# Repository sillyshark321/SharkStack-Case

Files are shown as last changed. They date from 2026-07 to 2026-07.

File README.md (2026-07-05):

# Corne v3 Stacked Acrylic Case
The whole project fits on a 3mm or 1/8" thick, 24" x 12" sheet of acrylic.
<div align="center">
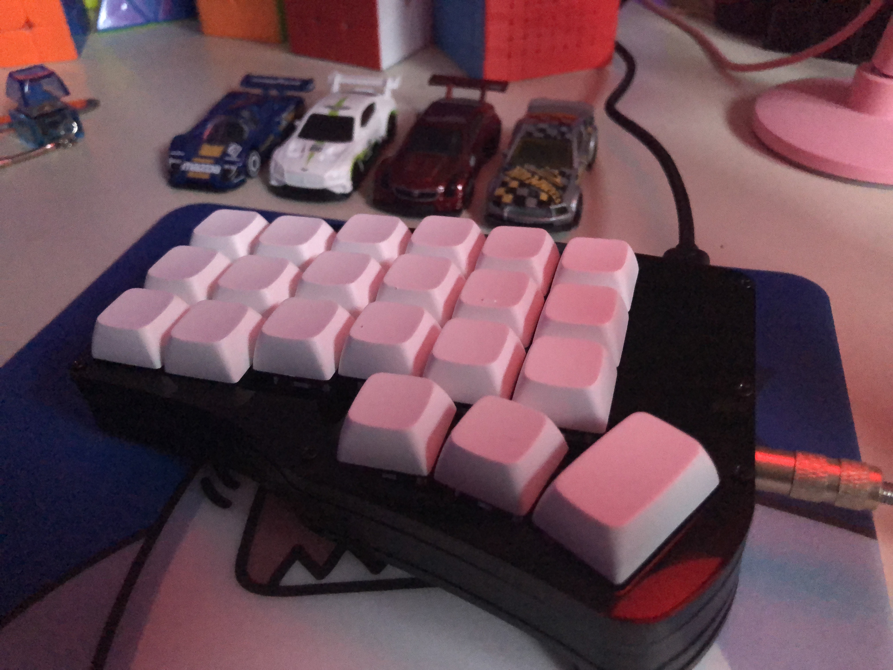
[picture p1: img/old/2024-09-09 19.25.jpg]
  
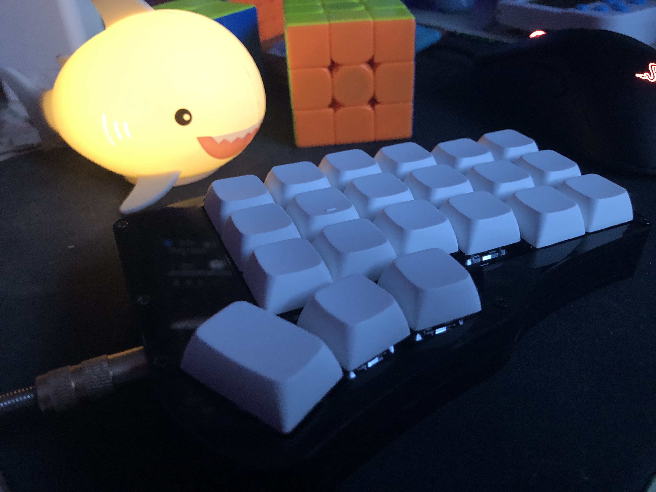
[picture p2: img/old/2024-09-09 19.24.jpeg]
  
</div>

<div align="center">
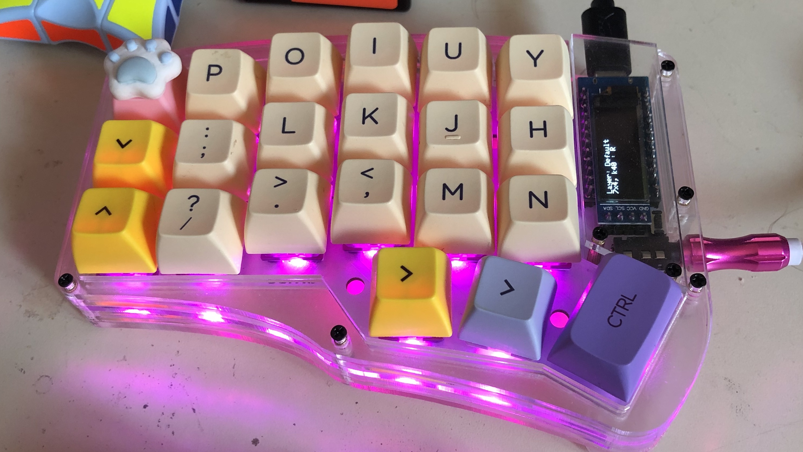
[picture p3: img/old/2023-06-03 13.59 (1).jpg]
  
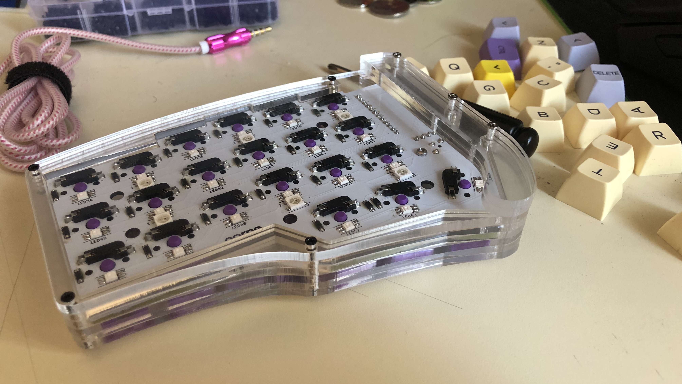
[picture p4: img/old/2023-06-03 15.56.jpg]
  
</div>

## Layers on cut file coloured
<div align="center">
  
</div>

## Materials List
| Material | Count | Notes |
| --- | --- | --- |
| **3 mm or 1/8" thick, 24" x 12" sheet of acrylic** | 1 | |
| **M2 x 12 mm standoffs** | 14 | You need 4 extra for the OLED cover (mounted to PCB)<br>I used 11 mm tall standoffs, works just fine |
| **M2 x 8 mm screws** | 22 | You need 28 without tenting |
| **M2 x 18 mm screws** | 6 | Only for tenting, adjust screw lengths if you wish to add more tenting layers |
| **Adhesive rubber feet** | 8 | Optional but highly recommended |

## Assembly
Finish your Corne v3 PCB first - I used [this guide](https://github.com/keyhive/build_guides/blob/master/docs/keyboards/crkbd-v3.md) from KeyHive

Download a .dxf file ([no OLED version](https://github.com/sillyshark321/SharkStack-Case/blob/main/dxf/sharkstack_noOLED.dxf) | [with OLED version](https://github.com/sillyshark321/SharkStack-Case/blob/main/dxf/sharkstack_withOLED.dxf)) and cut the patterns on your acrylic sheet. Make sure it is 3 mm thick.

Attach 4 standoffs to the outer sides of the base pieces, and screw them in with your short M2 screws.

<div align="center">
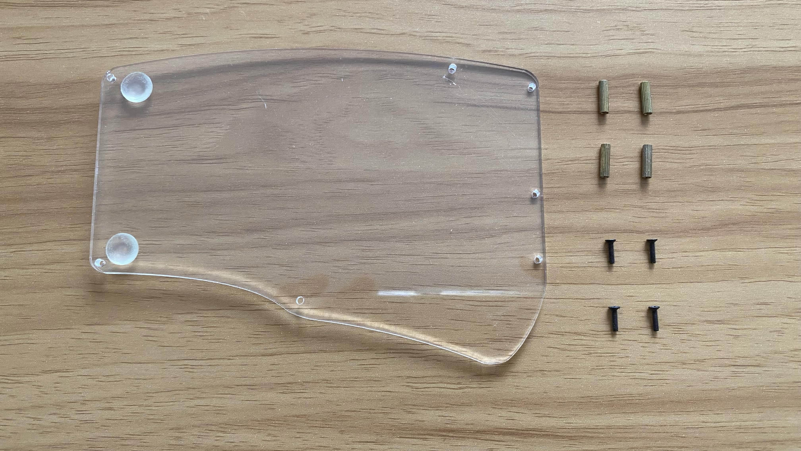
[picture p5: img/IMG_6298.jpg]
  
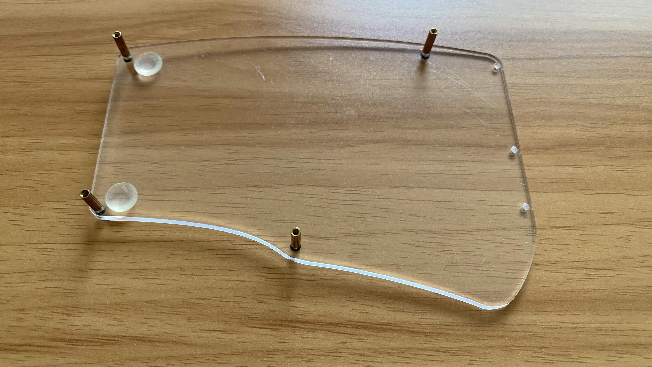
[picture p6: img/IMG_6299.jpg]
  
</div>

\
Stack your tenting layers (3 on each side in the cut file), and secure them to the base with the rest of your standoffs and your longer M2 screws.

<div align="center">
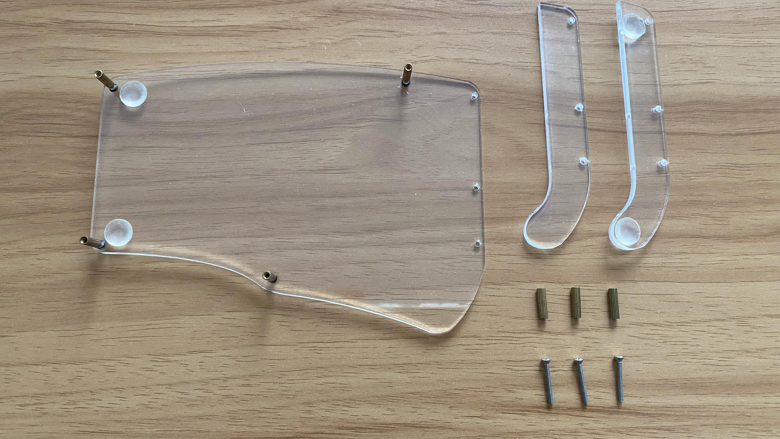
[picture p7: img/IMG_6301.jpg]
  
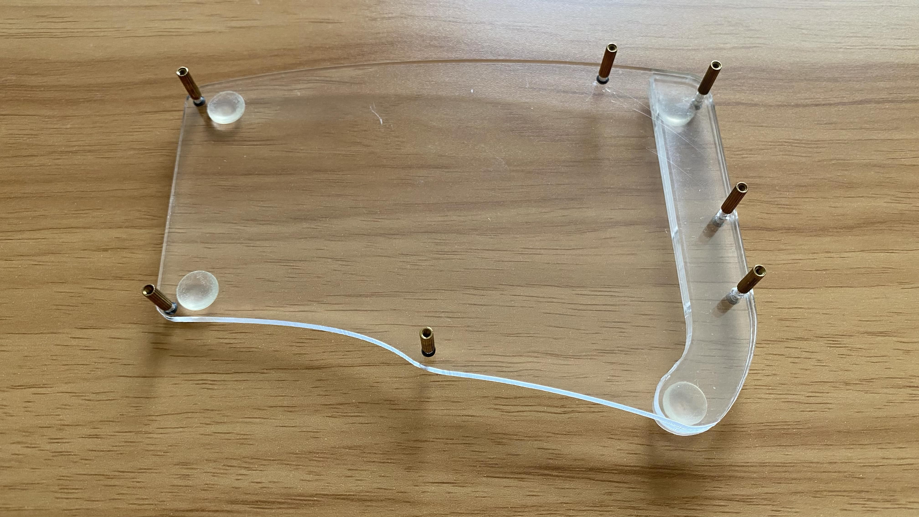
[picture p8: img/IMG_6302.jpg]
  
</div>

\
Add 2 big wall layers and 4 short wall layers through the standoffs, as shown here.

<div align="center">
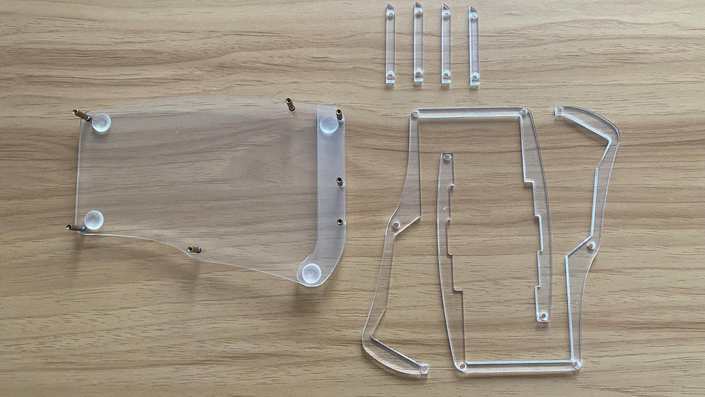
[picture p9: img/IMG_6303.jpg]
  
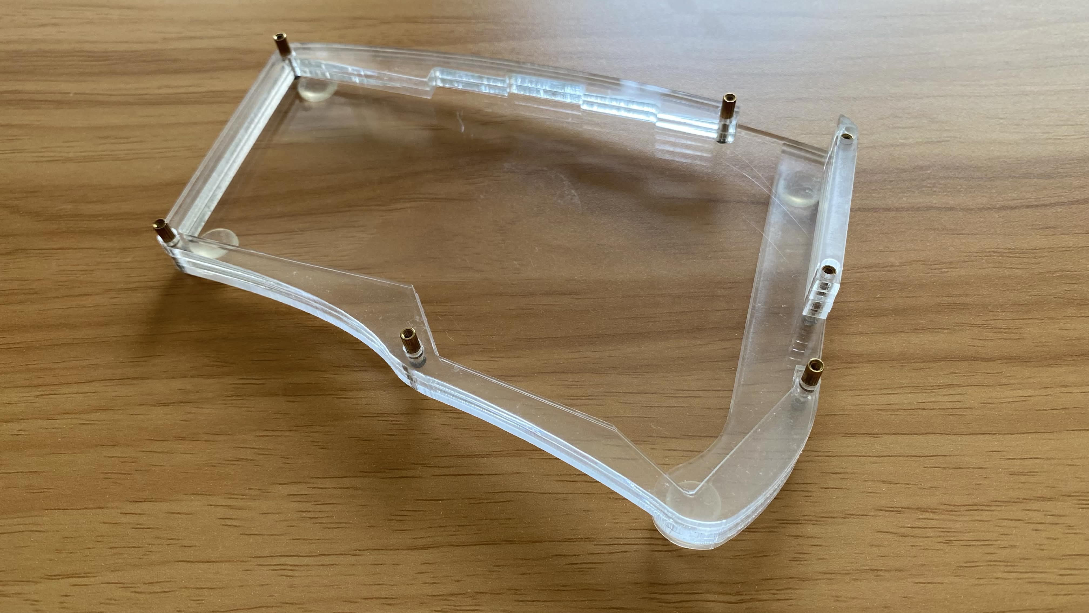
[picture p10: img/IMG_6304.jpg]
  
</div>

\
Add your desired switches onto your plate layers, and mount the Corne v3 PCBs to the switches. Put them in the case.\
Solder PCBs are recommended, but hotswap PCBs work fine too as long as you press firmly. Also attach your OLED covers with your extra standoffs if needed.

<div align="center">
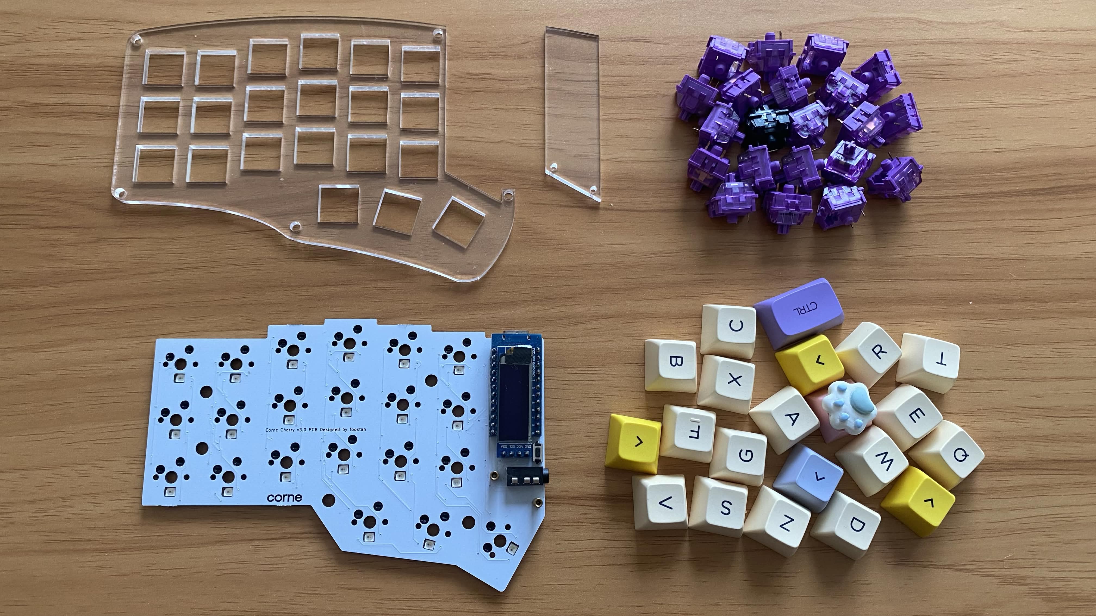
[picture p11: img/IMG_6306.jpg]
  
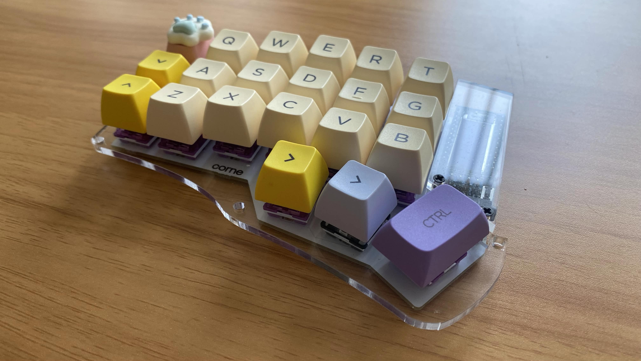
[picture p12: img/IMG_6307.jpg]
  
</div>

<div align="center">
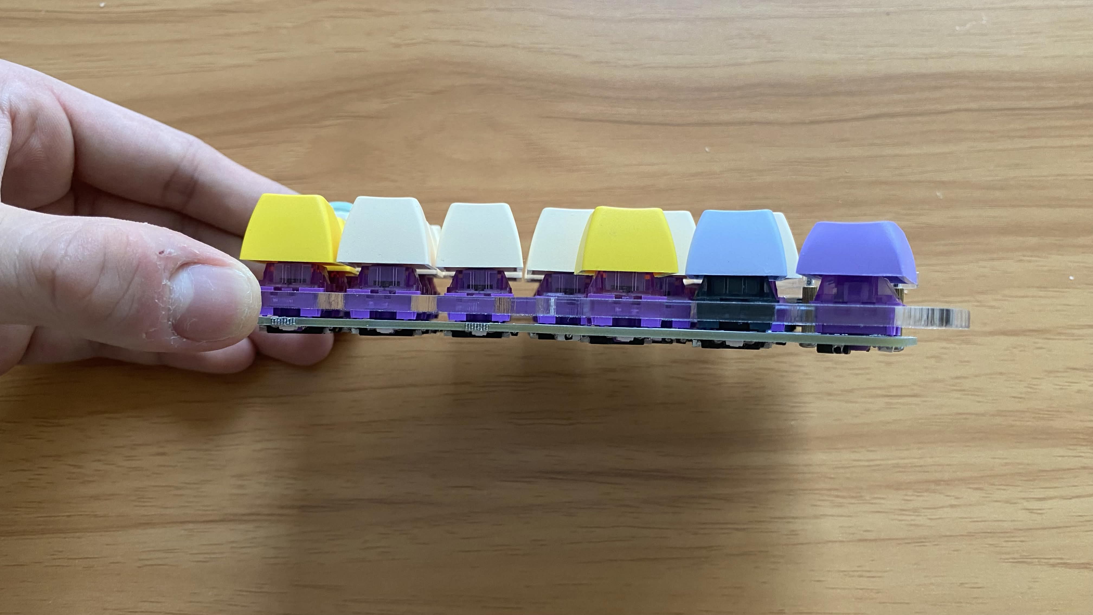
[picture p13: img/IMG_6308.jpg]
  
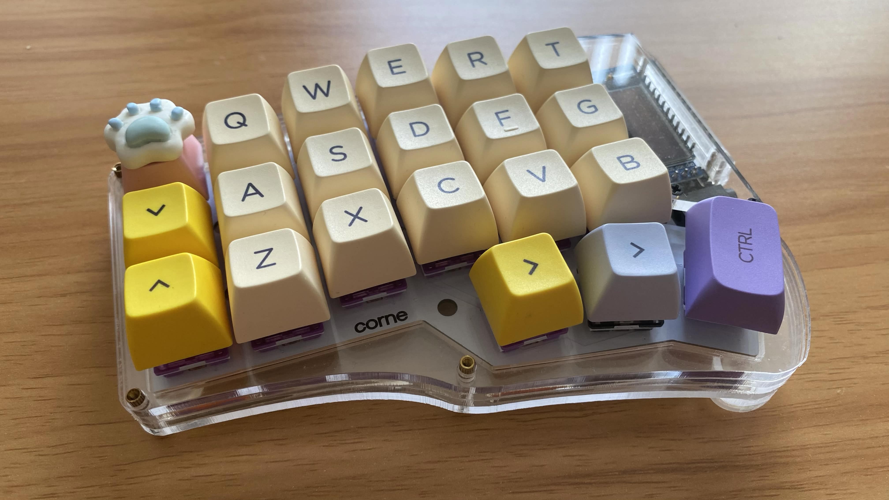
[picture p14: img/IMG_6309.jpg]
  
</div>

\
If you wish to use the version with no OLED cover, you may need to trim the pin headers, as this would happen otherwise.

<div align="center">
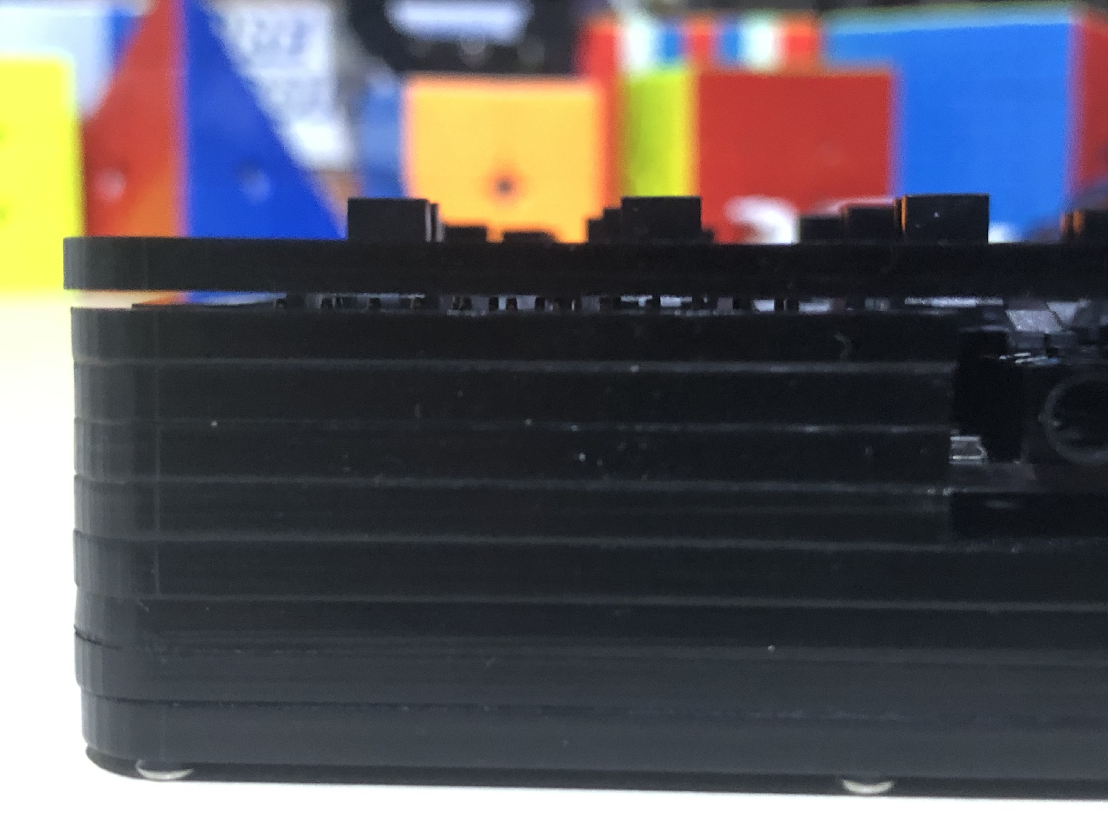
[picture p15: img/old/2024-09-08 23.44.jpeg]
  
</div>

\
Add the last wall layer, and add the top layer on top of the standoffs, and secure the case with the rest of your short M2 screws. Add adhesive rubber feet to finish it off.

<div align="center">
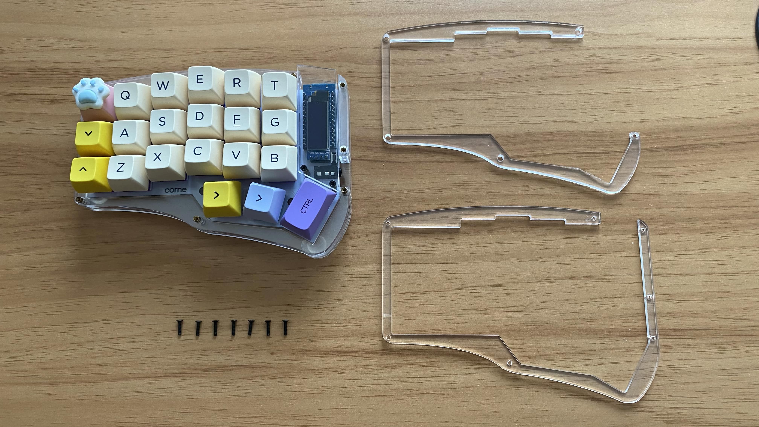
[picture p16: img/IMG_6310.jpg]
  
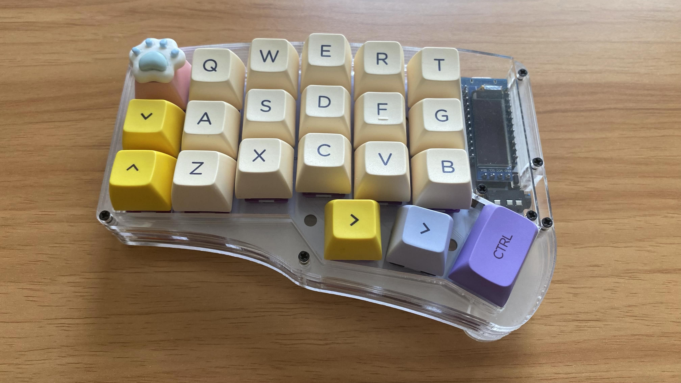
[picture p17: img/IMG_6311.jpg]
  
</div>

<div align="center">
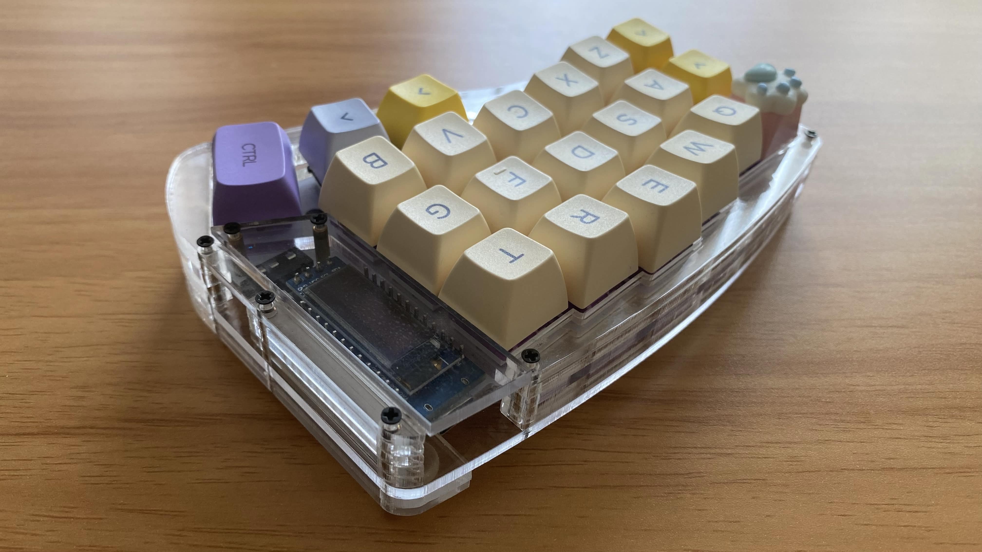
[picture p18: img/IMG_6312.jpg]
  
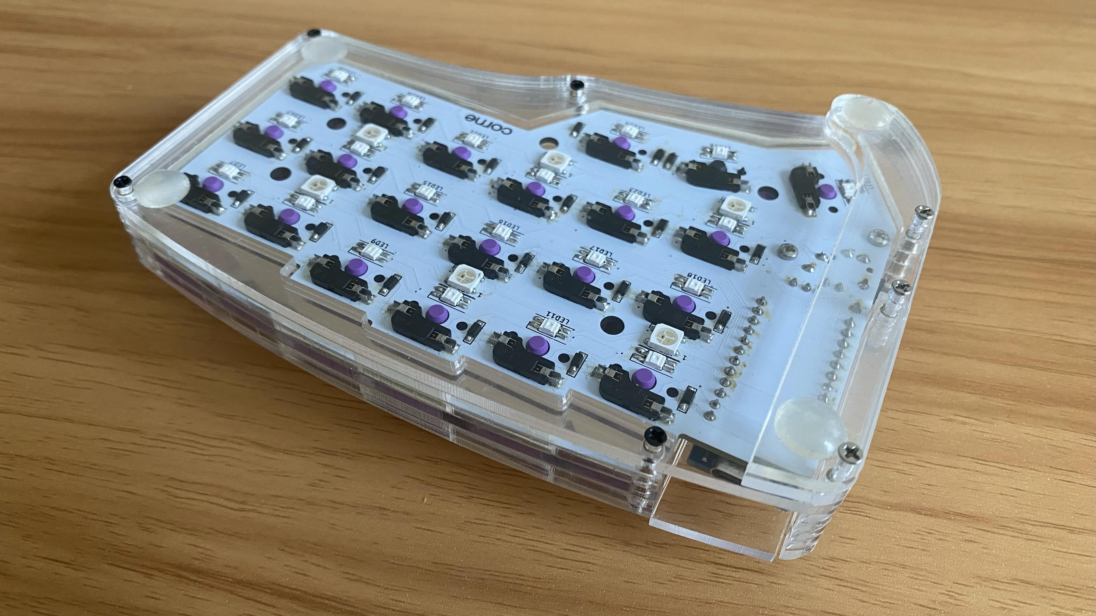
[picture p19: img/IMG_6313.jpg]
  
</div>

\
Repeat for the other half of your keyboard. Now you are done!
<div align="center">
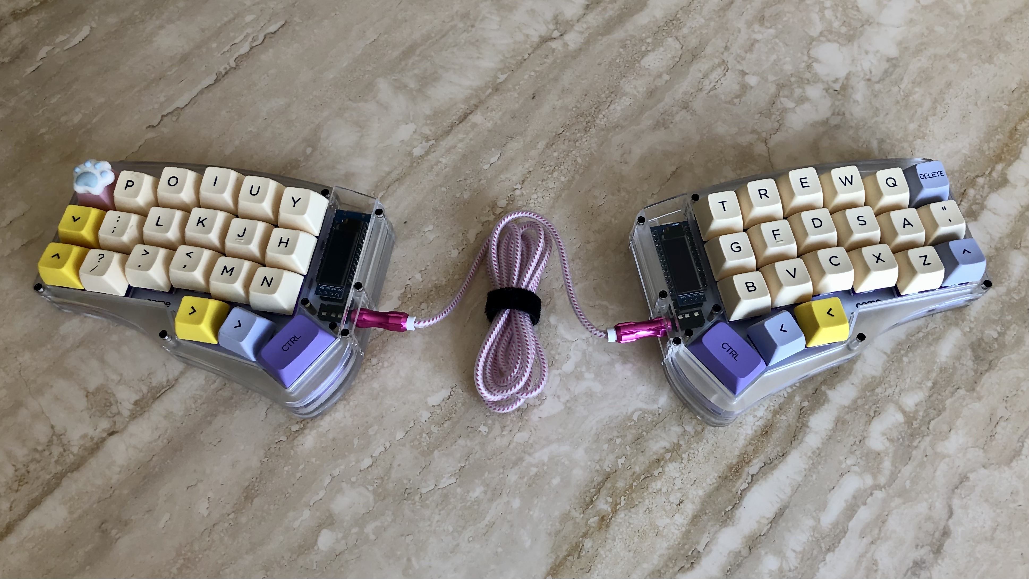
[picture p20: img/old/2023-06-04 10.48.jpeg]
  
</div>

## Watch me type because I'm pretty fast
<a href="https://www.youtube.com/watch?v=AXg2ITo80VI">
  <div align="center">
    
  </div>
</a>

## Other Links
This project was made possible (and heavily inspired) by Joe Scotto's keyboard case designing video:\
https://www.youtube.com/watch?v=7azQkSu0m_U

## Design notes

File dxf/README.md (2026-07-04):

# Cut Files
File names are self-explanatory. The only differences are the topmost layer, where a few extra cuts are included for the OLED covers.

All files have been tested with my two Corne builds. However, since they were backed up from another CAD software, the splines are slightly messed up and the cut lines aren't joined. I will take that into consideration when making future stacked acrylic keyboard cases.

## Author's Note
Turn up your cut strength settings slightly. I used the 60W Epilog Fusion Edge 24 and a few lines on the bottom half of my acrylic sheet didn't cut all the way through.

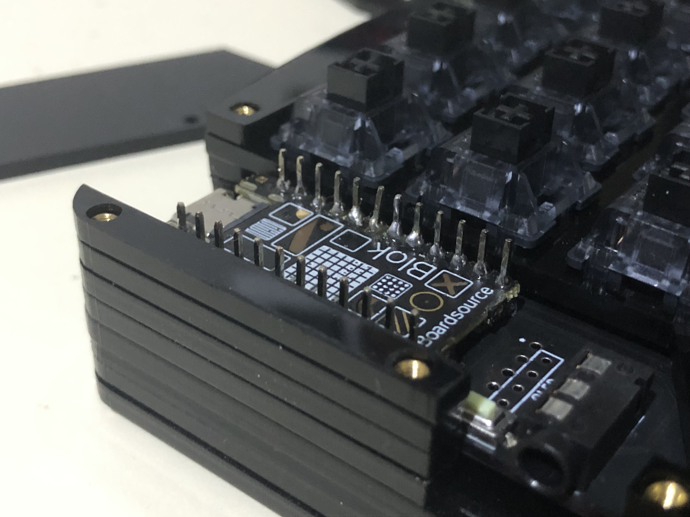
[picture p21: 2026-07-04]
img/2024-09-08 23.44 (1).jpeg

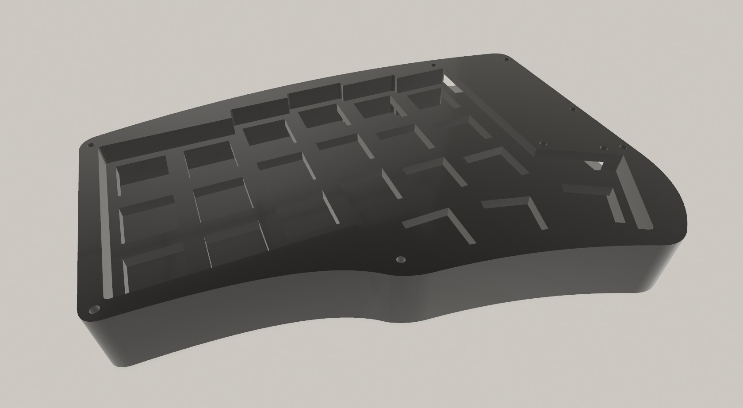
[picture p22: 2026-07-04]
img/2023-05-23 07.58.png

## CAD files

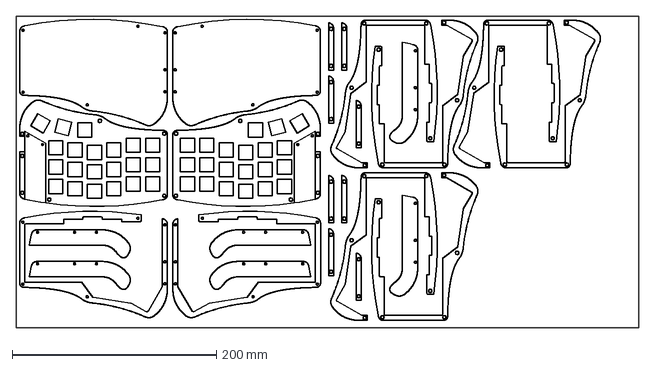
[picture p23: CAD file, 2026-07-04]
dxf/sharkstack_withOLED.dxf
609.6 x 304.8 mm

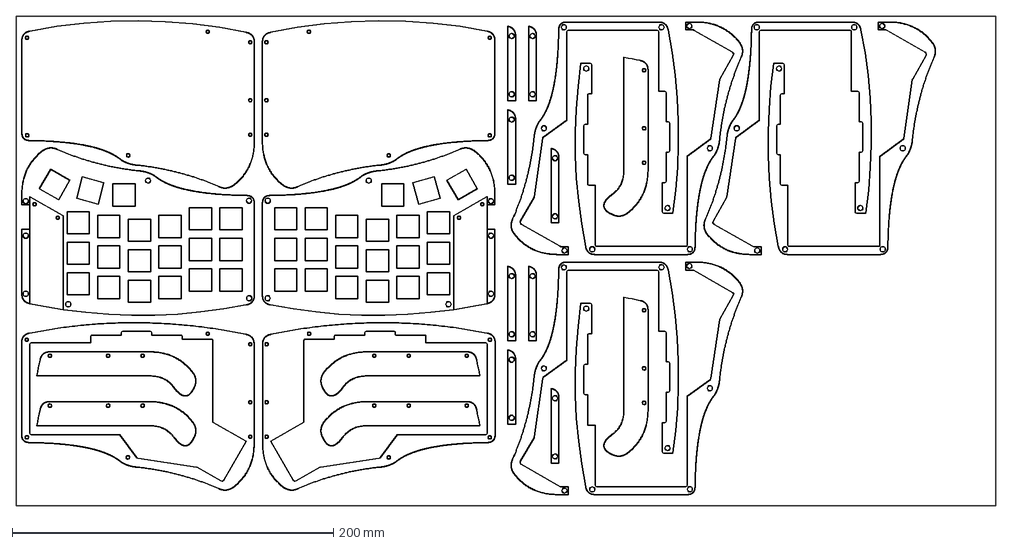
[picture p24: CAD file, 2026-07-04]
dxf/sharkstack_noOLED.dxf
609.6 x 304.8 mm
